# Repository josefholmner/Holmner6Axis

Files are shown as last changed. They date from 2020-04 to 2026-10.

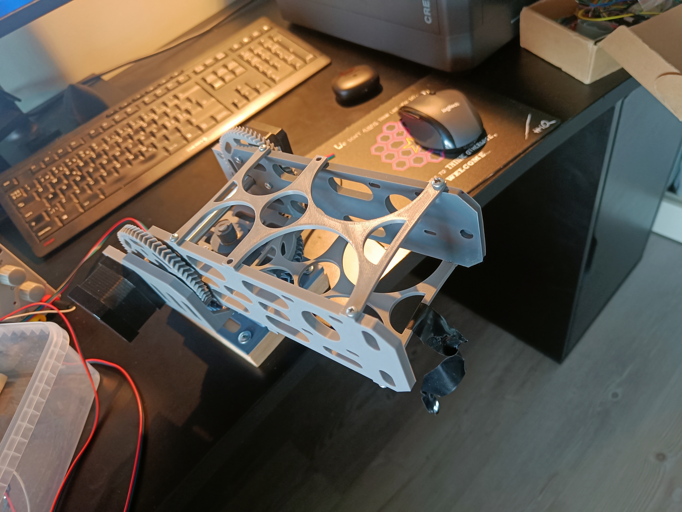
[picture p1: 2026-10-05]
Experiments/MotorTorqueTest2/setup2.jpg

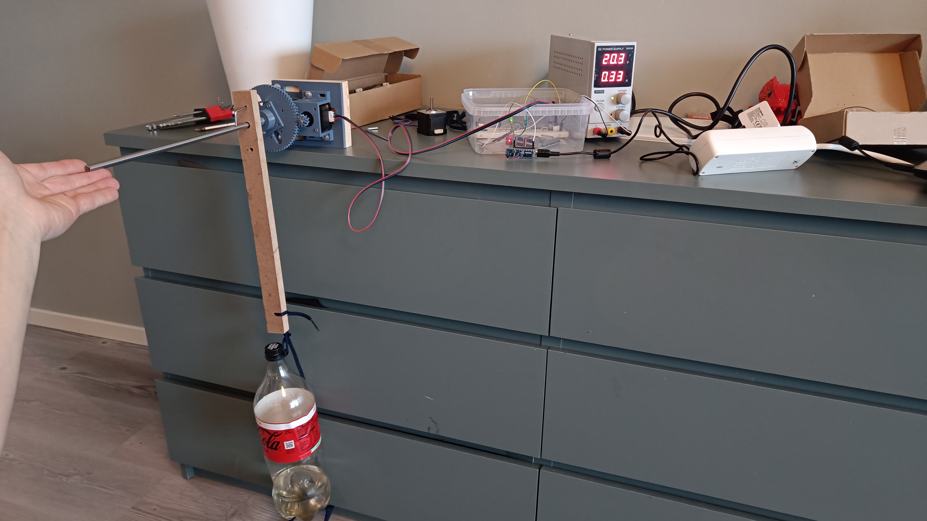
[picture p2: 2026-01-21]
Experiments/MotorTorqueTest/ExperimentSetup.jpg

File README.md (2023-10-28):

# Holmner6Axis (Under construction...)

This project started in May 2020. Made By Josef Holmner.

A DIY 6 axis robot made more or less from scratch. All the way from hardware, though software down to low level motor drivers.

New material will be uploded as the project progresses. One goal is to provide all material needed for anyone to build the same robot themselves. The current status of the project can be gathered by reading the progress below, which will grow as the project progresses.

## Progress (list will be appended to along the way)
- [x] Rough 3d-model
- [ ] Refined 3d-model ready for printing
- [x] Forward / inverse kinematics prototype script
- [ ] C++ motor driver
- [ ] Complete C++ application for Raspberry Pi 3

## Raspberry Pi setup
1. Install CMake (sudo apt-get install cmake).
2. Ensure pigpio is installed (included with Raspberry Pi OS).

Clone this repo to a Raspberry Pi.
To build, run the following from the repo root:

```
cd RaspberryPi/Holmner6Axis
mkdir build
cd build
cmake ..
sudo cmake --build . --config Release --target install
```

Now the application can be started by running:

```
sudo Holmner6Axis
```

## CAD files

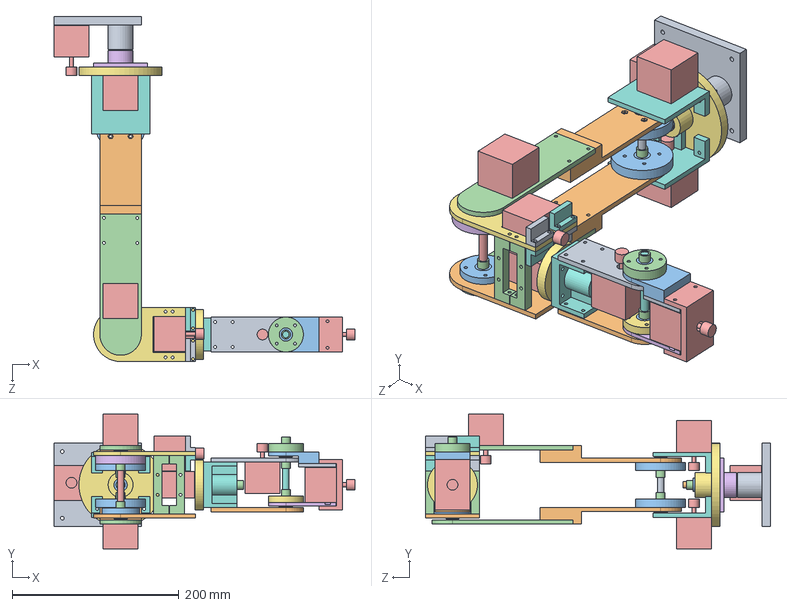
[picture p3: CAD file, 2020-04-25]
3D-models/SolidWorksProject/Holmner6Axis_Assembly.SLDASM
361.5 x 162.0 x 414.5 mm
Axis0_BottomPlate
Axis1_Rod
BallBearing x 16
ShaftCoupler x 9
StepperMotor x 7
Axis1_CogHolder
Axis1_Cog
Axis2_Holder x 2
Axis2_Rod
Axis2_Arm_1 x 2
Axis2_Cog x 2
Axis2_Arm_2 x 2
Axis3_Rod
Axis3_Cog
Axis4_Arm_1_Left
Axis4_MotorHolder_Right x 2
Axis4_MotorHolder_Left x 2
Axis4_Arm_1_Right
Axis3_BearingEnd
Axis4_Holder x 4
Axis4_RodHolder
Axis4_Rod
Axis4_Cog
Axis4_RodEnd
Axis4_Arm_2_Left
Axis4_Arm_2_Right
Axis5_Arm_1_Left
Axis5_Cog
Axis6_MotorHolder
Axis5_Arm_Right
Axis5_BearingHolder
Axis5_Rod
Axis5_Arm_2_Left

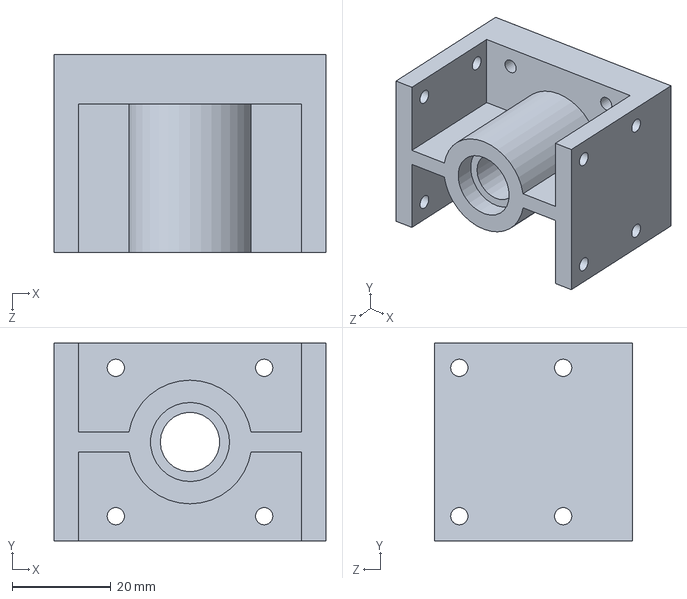
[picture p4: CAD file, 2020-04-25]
3D-models/SolidWorksProject/Axis4_RodEnd.SLDPRT
55.0 x 40.0 x 40.0 mm

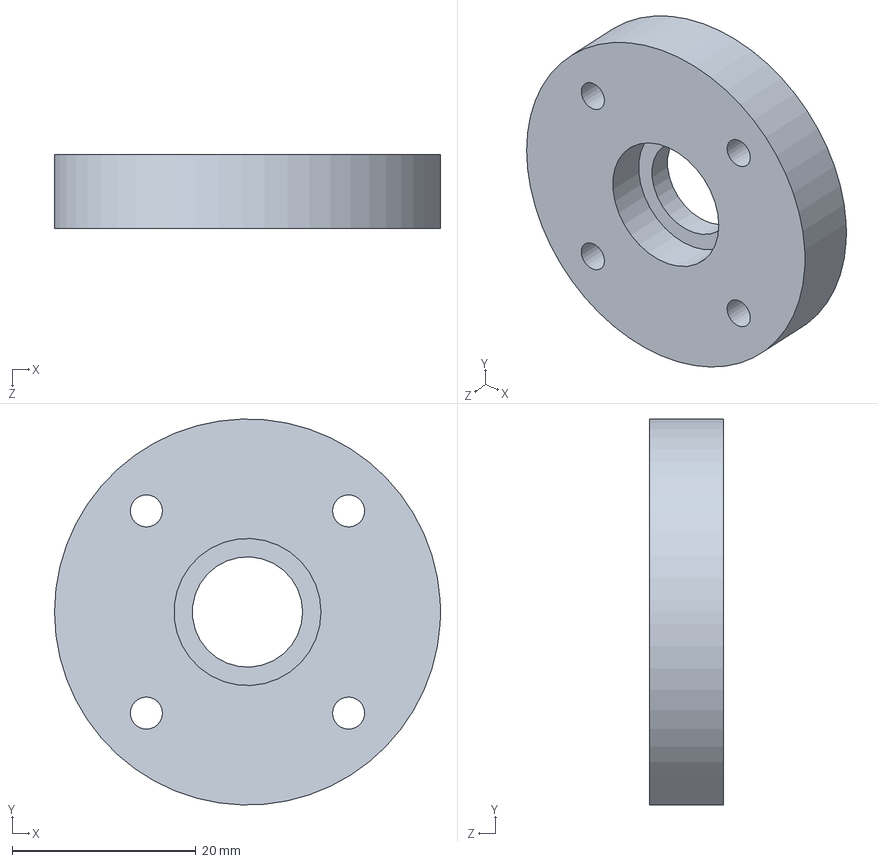
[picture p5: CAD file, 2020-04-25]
3D-models/SolidWorksProject/Axis5_BearingHolder.SLDPRT
42.0 x 42.0 x 8.00 mm

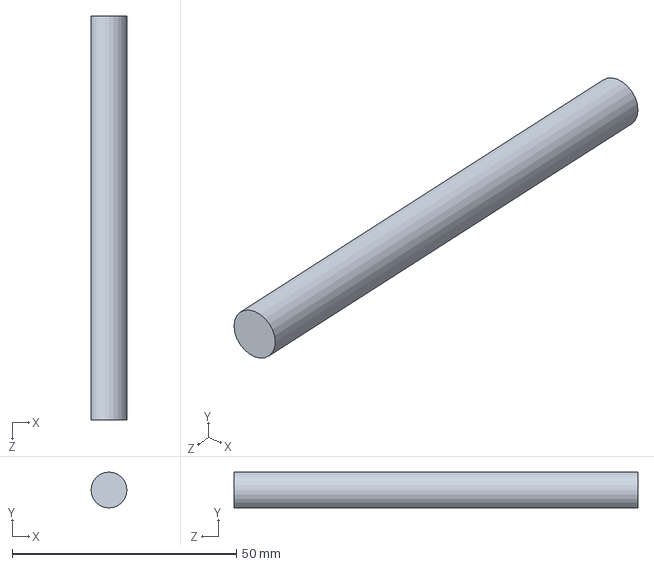
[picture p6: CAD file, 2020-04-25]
3D-models/SolidWorksProject/Axis3_Rod.SLDPRT
8.00 x 8.00 x 90.0 mm

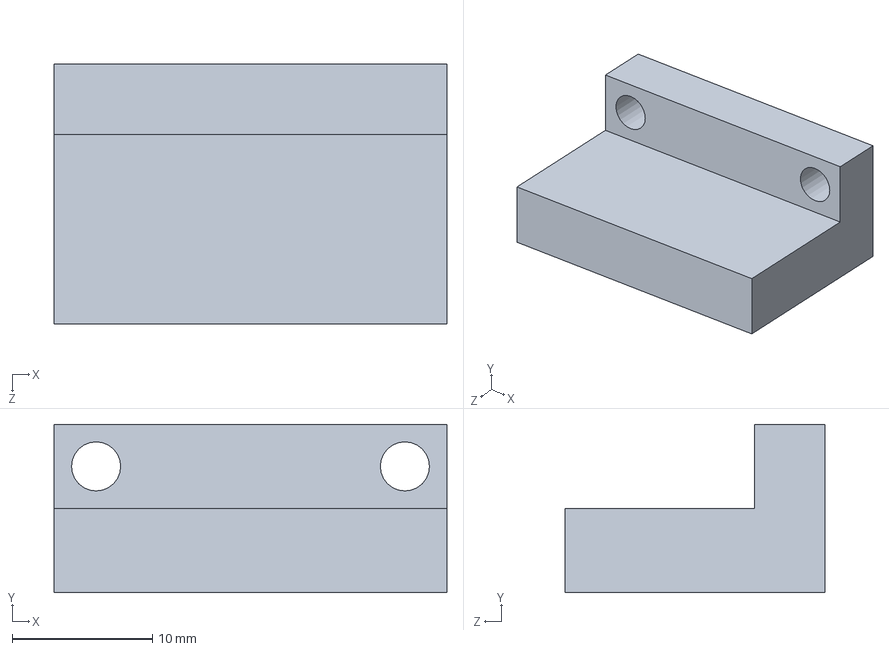
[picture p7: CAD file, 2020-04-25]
3D-models/SolidWorksProject/Axis4_MotorHolder_Right.SLDPRT
28.0 x 12.0 x 18.5 mm

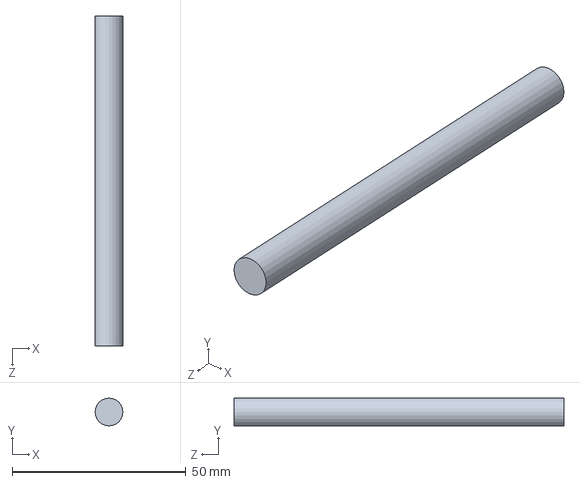
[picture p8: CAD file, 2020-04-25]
3D-models/SolidWorksProject/Axis1_Rod.SLDPRT
8.00 x 8.00 x 95.0 mm

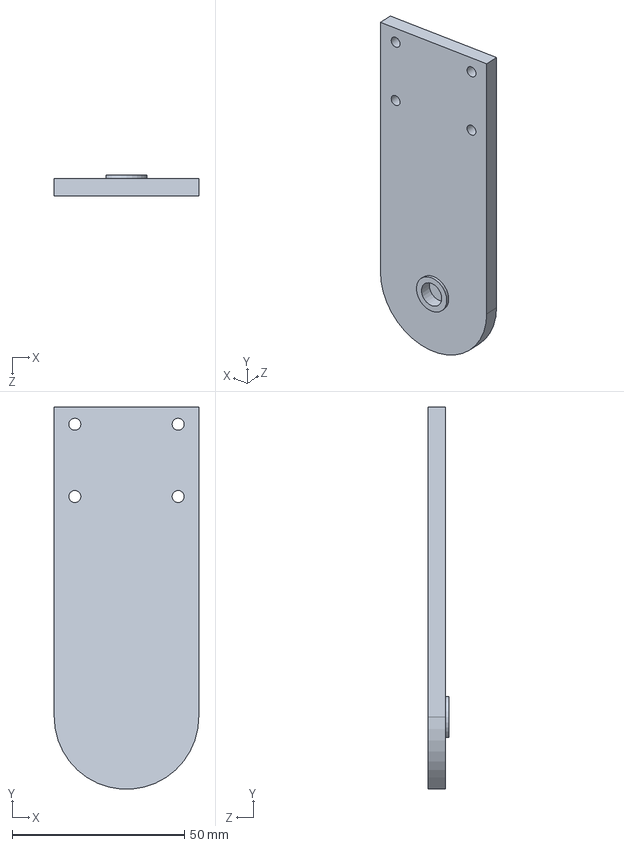
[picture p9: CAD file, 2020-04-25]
3D-models/SolidWorksProject/Axis4_Arm_2_Right.SLDPRT
42.0 x 110.9 x 6.00 mm

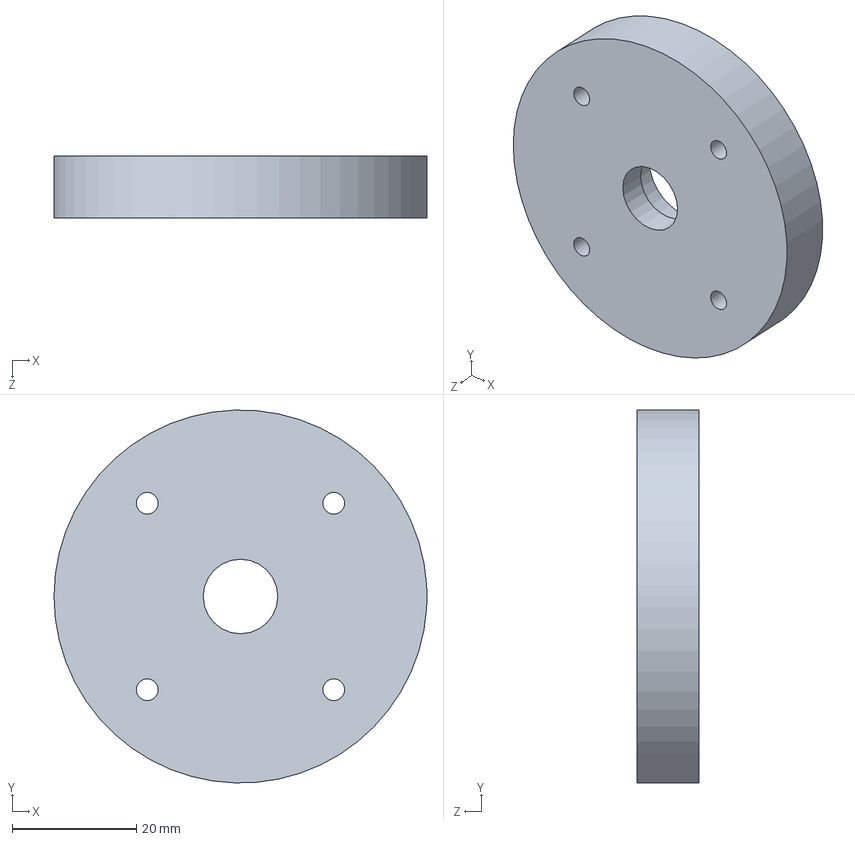
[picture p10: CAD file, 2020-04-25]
3D-models/SolidWorksProject/Axis4_Cog.SLDPRT
60.0 x 60.0 x 10.0 mm

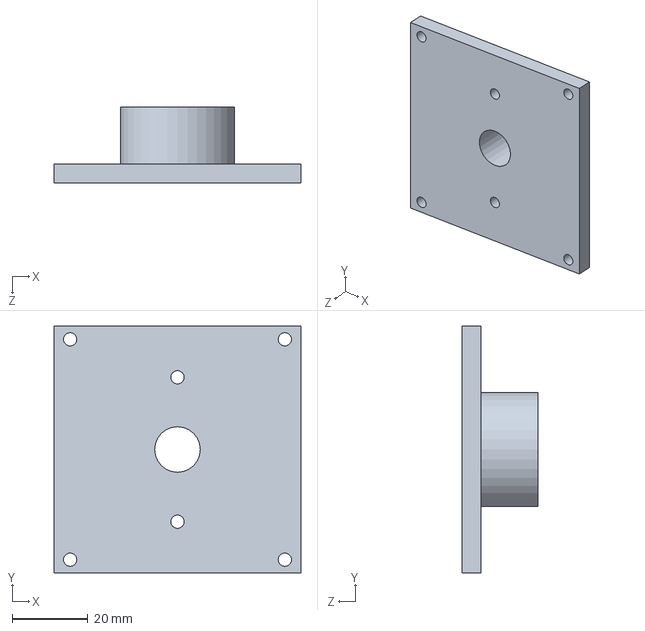
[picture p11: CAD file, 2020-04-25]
3D-models/SolidWorksProject/Axis1_CogHolder.SLDPRT
65.0 x 65.0 x 20.0 mm

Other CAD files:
3D-models/FreeCad/Assembly.FCStd
3D-models/FreeCad/Axis2_Distance.FCStd
3D-models/FreeCad/MotorCog_9mm.FCStd
3D-models/FreeCad/MotorCog_7mm_v2.FCStd
3D-models/FreeCad/Axis2_Cog_v2.FCStd
3D-models/FreeCad/Axis2_Bracket_Right.FCStd
3D-models/FreeCad/Axis2_Arm_left_v2.FCStd
3D-models/FreeCad/Axis2_Arm_right_v2.FCStd
3D-models/FreeCad/Axis2_arm_fuse.FCStd
3D-models/FreeCad/Axis1_Cog.FCStd
3D-models/FreeCad/Axis1_MotorMount.FCStd
3D-models/FreeCad/Axis1_Rod.FCStd
3D-models/FreeCad/Axis1_RodStop.FCStd
3D-models/FreeCad/Axis2_Bracket_Left.FCStd
3D-models/FreeCad/Axis2_LowerArm.FCStd
3D-models/FreeCad/Axis3_Arm.FCStd
3D-models/FreeCad/Axis3_Cog.FCStd
3D-models/FreeCad/BallBearing.FCStd
3D-models/FreeCad/BasePlate.FCStd
3D-models/FreeCad/Motor.FCStd
3D-models/FreeCad/MotorCog_8mm.FCStd
3D-models/FreeCad/RodStop.FCStd
3D-models/SolidWorksProject/Axis0_BottomPlate.SLDPRT
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

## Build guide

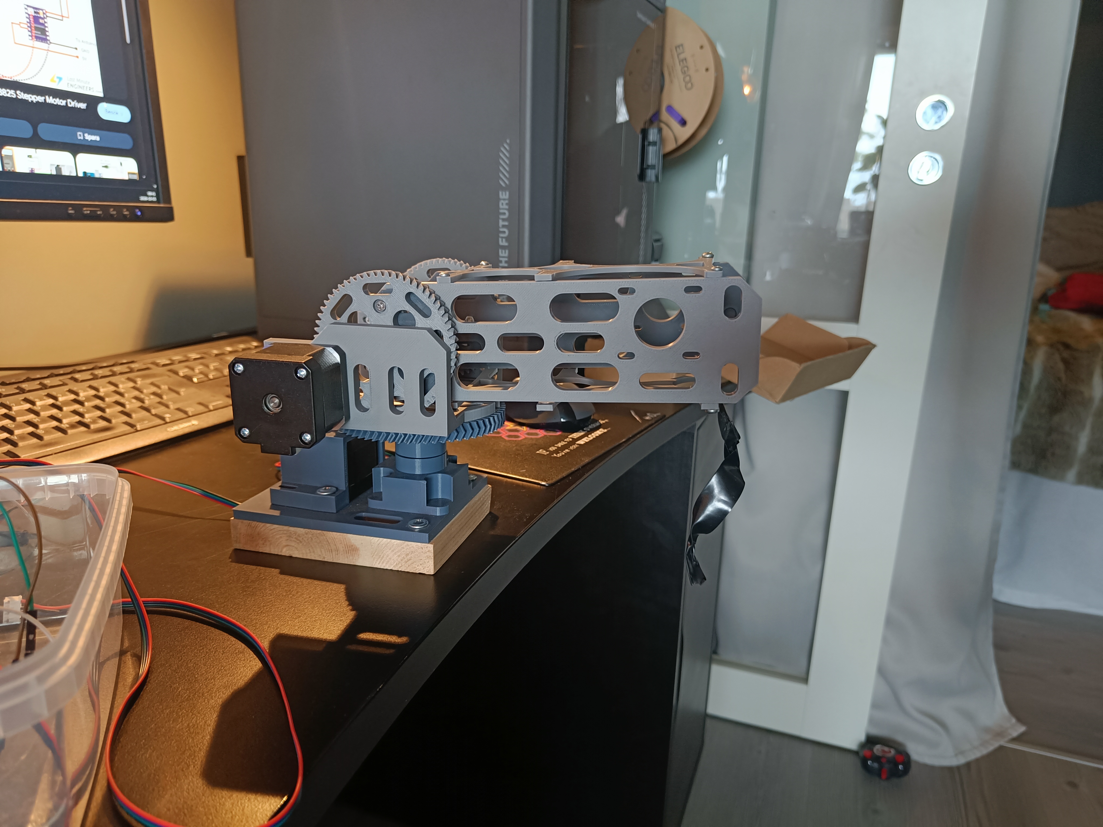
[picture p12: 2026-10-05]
Experiments/MotorTorqueTest2/setup1.jpg

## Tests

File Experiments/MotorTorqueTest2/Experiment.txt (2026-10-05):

Setup: 2 motors
Axis2 + 1.7 Kg additional weight lifted from vertical.

Gear ratio (per motor): 9/60 

Axis to weight distance = 175mm

More than 1.7kg additional weight meant motor skipping, NOT gear slipping!
Gear skipping did not occur and was ensured by a marker pen line on small and large cog.

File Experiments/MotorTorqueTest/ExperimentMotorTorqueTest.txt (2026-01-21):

Info:

Motor: Nema 17 HS4401S
Motor Driver: drv8825
Pulse generator: Atmel Atmega 328 (Arduino Nano)
Motor Driver in-voltage: 20v
Motor Driver step mode: 1/4 step
Small gear tooth count: 10 
Large gear tooth count: 65
Gear ratio: 2:13
Wooden rod weight: 0.129kg
End weight (bottle): 0.418kg
Axis to wooden rod center-of-mass distance: 0.145m
Axis to weight (bottle) attachment distance: 0.30m

----------------------
Execution:

The motor rotated the arm about 100 degrees from a vertical position.
The speed was low (500 deg/s on the motor side) but still high enough for a realistic axis1 movement.
A ramp was used to allow the speed to build up, but max speed was reached long before the movement mid-point. 
The motor was programmed to stop after about 100 degrees.

----------------------
Result:

At most, the end weight (bottle) maximum weight achieved was 0.418kg.
The nearest failing experiment was at about 0.460kg, so the real maximum is anywhere in between those values.
Failing was due to motor skipping internally, NOT due to cog slipping. This was carefully ensured using markers on each cog.

Motor torque calculation (when the arm is at 90 degrees):
Reaction torque due to rod center-of-mass: 0.129 * 9.81 * 0.145 = 0.18349605 Nm
Reaction torque due to end weight (bottle): 0.418 * 9.81 * 0.30 = 1.230174 Nm
Sum of torques on arm-side (after gears): 0.18349605 + 1.230174 = 1.41367005 Nm
Motor torque: 1.41367005 * (2/13): 0.2174877 Nm

Result: Torque at the motor shaft during movement AT LEAST 0.2174877 Nm, likely a bit higher.

---------------------
Notes:

The Atmel Atmega 328 was used instead of a Raspberry Pi to ensure a clean stepping signal.

Running the motor in full-step mode (which should give higher torque according to many sources) caused the motor to give out lots of noise and the torque before slipping was greatly REDUCED.
Not sure why. A different motor was tested as well, with the same result. Might be due to a faulty Motor Driver. The pulse generating code was altered to compensate for the different step mode.
Running the motor in 1/8 step mode also made the motor run slower than expected.
I think the tests with the other stepping modes should be taken with a grain of salt since I did not get the motor to behave as expected.

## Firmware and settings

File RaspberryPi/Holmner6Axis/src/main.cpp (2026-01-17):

// Pigpio includes.
#include <pigpio.h>

// Standard library includes.
#include<cmath>
#include <iostream>
#include <thread>
#include <vector>

std::vector<double> calcRamp(double angleGoal, double wMax, double maxAcc, double stepAngle)
{
    const double a = maxAcc;
    const double th3 = angleGoal;
    const double t1 = wMax / a;
    const double th1 = wMax * wMax / (2.0 * a);
    const double th2 = th3 - th1;
    const double t2 = t1 + (th2 - th1) / wMax;

    std::vector<double> ts;
    ts.reserve(static_cast<size_t>(1.0 + th3 / stepAngle));
    double th = stepAngle;
    
    while (th < th1)
    {
        ts.push_back(sqrt(2.0 * th / a));
        th += stepAngle;
    }

    while (th < th2)
    {
        ts.push_back(t1 + (th - th1) / wMax);
        th += stepAngle;
    }

    while (th <= th3)
    {
        ts.push_back(t2 + wMax / a - sqrt(pow(wMax/a, 2.0) - 2.0 * (th - th2) / a));
        th += stepAngle;
    }

    return ts;
}

void executeRamp(int pin, const std::vector<double>& ts)
{
    if (gpioSetMode(pin, PI_OUTPUT) != 0)
    {
        std::cerr << "gpioSetMode failed\n";
        return;
    }

    gpioWrite(pin, 0);
    
    const size_t Max = ts.size();
    const uint32_t startTime = gpioTick();
    for (size_t i = 1; i < Max; i++)
    {
        // double t in seconds and uint32_t times in microseconds.
        const uint32_t mid_step_rel_time = static_cast<uint32_t>((ts[i-1] + ts[i]) / 2.0 * 1000000.0);
        const uint32_t step_rel_time = static_cast<uint32_t>(ts[i] * 1000000.0);
        const uint32_t mid_step_wall_time = startTime + mid_step_rel_time;
        const uint32_t step_wall_time = startTime + step_rel_time;

        while (gpioTick() < mid_step_wall_time){}
        gpioWrite(pin, 1);
        while (gpioTick() < step_wall_time){}
        gpioWrite(pin, 0);
    }

    const uint32_t endTime = gpioTick();
    std::cout << "Total time: " << endTime - startTime << "us.\n";
    std::cout << "Total steps: " << ts.size() << ".\n";
}

int main()
{
    std::cout << "Hello from Holmner6Axis\n";

    if (gpioInitialise() < 0)
    {
        std::cerr << "gpioInitialize failed\n";        
        return 1;
    }

    const std::vector<double> ramp = calcRamp(2160.0, 2000.0, 2000.0, 0.45);
    executeRamp(21, ramp);
    gpioTerminate();
    return 0;
}

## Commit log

2020-04-25 First rough 3d cad models - solidworks project
    [Axis0_BottomPlate.SLDPRT, Axis1_Cog.SLDPRT, Axis1_CogHolder.SLDPRT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]
2020-04-25 Rename folder
    [Axis0_BottomPlate.SLDPRT, Axis1_Cog.SLDPRT, Axis1_CogHolder.SLDPRT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]
2020-04-25 Add prototype script for forward and inverse kinematics
2020-04-26 Organize kinematic prototype script
2021-01-09 Implement basic i2c slave that can receive 4 bytes of data over i2c
2021-01-09 Add Atmega328 support for receiving array of floats over i2c
2021-01-11 Add basic I2C master functionality to Pi application
2021-01-13 Add basic structure of the RPI application
    [Configuration.h]
2021-01-13 Update readme with i2c setup info
2021-01-23 Implement circular buffer with motor commands in motor stepper
2023-10-28 Clean up and prepare for full sw rewrite
    [Configuration.h]
2023-11-11 Simple motor ramp test code
2026-01-09 Start adding FreeCad cad files
    [BallBearing.FCStd, BasePlate.FCStd, Motor.FCStd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]
2026-01-09 Add axis1 parts
    [Assembly.FCStd, Axis1_MotorMount.FCStd, Axis1_Rod.FCStd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]
2026-01-10 Update baseplate and motor mount 1
    [Assembly.FCStd, Axis1_MotorMount.FCStd, BasePlate.FCStd]
2026-01-11 Add rod stop for axis 1
    [Assembly.FCStd, Axis1_MotorMount.FCStd, Axis1_Rod.FCStd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]
2026-01-11 Axis2 bracket work
    [Assembly.FCStd, Axis1_MotorMount.FCStd, Axis2_BottomBrackets.FCStd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]
2026-01-11 Fixup axis 2
    [Assembly.FCStd, Axis2_BottomBrackets.FCStd]
2026-01-11 More Axis2 tweaking
    [Assembly.FCStd, Axis1_MotorMount.FCStd, Axis1_RodStop.FCStd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]
2026-01-11 Finalize axis 2 design
    [Assembly.FCStd, Axis1_MotorMount.FCStd, Axis1_Rod.FCStd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]
2026-01-11 Update axis1 cog routing hole
    [Assembly.FCStd]
2026-01-12 Update ballbearing hole size
    [Assembly.FCStd, Axis1_Cog.FCStd, Axis2_LowerArm.FCStd]
2026-01-12 Update rodstop
    [Assembly.FCStd, Axis1_RodStop.FCStd]
2026-01-13 Make cog1 a bit thicker and add general rodstop
    [Assembly.FCStd, Axis1_Cog.FCStd, Axis1_Cog_old.FCStd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]
2026-01-17 Baseplate redesign
    [Assembly.FCStd, BasePlate.FCStd]
2026-01-17 Update motor1 cogs
    [Assembly.FCStd, Axis1_Cog.FCStd, Axis1_Cog_old.FCStd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]
2026-01-17 Adjust axis2 cogs
    [Assembly.FCStd, Axis2_BottomBrackets.FCStd, Axis2_Cog.FCStd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]
2026-01-18 Update axis 2 cogs
    [Assembly.FCStd, Axis2_Cog.FCStd, MotorCog_8mm.FCStd]
2026-01-18 Update bottombracket axis2
    [Assembly.FCStd, Axis2_BottomBrackets.FCStd, Axis2_Cog.FCStd]
2026-01-18 Genral fixes axis 2 clearance
    [Assembly.FCStd, Axis2_BottomBrackets.FCStd, Axis2_Cog.FCStd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]
2026-01-18 Prepare for axis 3
    [Assembly.FCStd, Axis2_Cog.FCStd, Axis2_LowerArm.FCStd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]
2026-01-18 More axis3 work and some adjustments on axis 2
    [Assembly.FCStd, Axis1_MotorMount.FCStd, Axis2_LowerArm.FCStd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]
2026-01-19 Axis2 bracket redisign
    [Assembly.FCStd, Axis1_MotorMount.FCStd, Axis2_BottomBrackets.FCStd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]
2026-01-27 Axis2 redesign again
    [Assembly.FCStd, Axis2_Bracket_Left.FCStd, Axis2_Cog_v2.FCStd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]
2026-01-27 Axis2 redesign outline finished
    [Assembly.FCStd, Axis2_Arm_v2.FCStd, Axis2_Bracket_Left.FCStd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]
2026-01-28 Start making attachment holes for axis2 bracket
    [Assembly.FCStd, Axis2_Arm_v2.FCStd, Axis2_Bracket_Left.FCStd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]
2026-01-29 Axis2 parts holes
    [Assembly.FCStd, Axis2_Arm_v2.FCStd, Axis2_Bracket_Left.FCStd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]
2026-01-29 Minor adjustemts axis2 and axis1 cog holes
    [Assembly.FCStd, Axis1_Cog.FCStd, Axis2_Bracket_Left.FCStd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]
2026-01-31 Add support for axis2 bracket
    [Assembly.FCStd, Axis2_Bracket_Left.FCStd]
2026-01-31 Minor fixes
    [Assembly.FCStd, Axis2_Arm_v2.FCStd, Axis2_Bracket_Left.FCStd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]
2026-02-01 Make holes for cross-bar axis2
    [Assembly.FCStd, Axis2_Arm_v2.FCStd]
2026-02-10 Add axis2 distance piece
    [Assembly.FCStd, Axis2_Cog_v2.FCStd, Axis2_Distance.FCStd]
2026-09-27 Add axis2 fuse part
    [Assembly.FCStd, Axis2_Arm_v2.FCStd, Axis2_arm_fuse.FCStd]
2026-09-28 Minor upgrades
    [Axis2_Arm_left_v2.FCStd, Axis2_Arm_right_v2.FCStd, Axis2_Arm_v2.FCStd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]
2026-09-28 Minor updates
    [Axis2_Distance.FCStd, MotorCog_7mm_v2.FCStd, MotorCog_9mm.FCStd]
2026-09-28 Update distance axis2
    [Axis2_Distance.FCStd]
